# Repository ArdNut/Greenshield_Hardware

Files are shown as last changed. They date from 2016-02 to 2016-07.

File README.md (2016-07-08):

# Greenshield Hardware

This repository contains the design artifacts for the circuit and PCB layout
of the Greenshield Arduino shield created for chapter 10 of "Arduino: A Technical Reference".

These were creating using CadSoft's Eagle design tool version 6.5.0 for Linux.

Copyight 2015-2016 John M. Hughes

O'Reilly appreciates, but does not require, attribution. An attribution usually
includes the title, author, publisher, and ISBN. For example:

Arduino: A Technical Reference, by John M. Hughes. Copyright 2016 O’Reilly
Media, Inc., ISBN: 978-1-4919-2176-0.

If you feel your use of code examples falls outside fair use or the permission
given above, feel free to contact permissions@oreilly.com.

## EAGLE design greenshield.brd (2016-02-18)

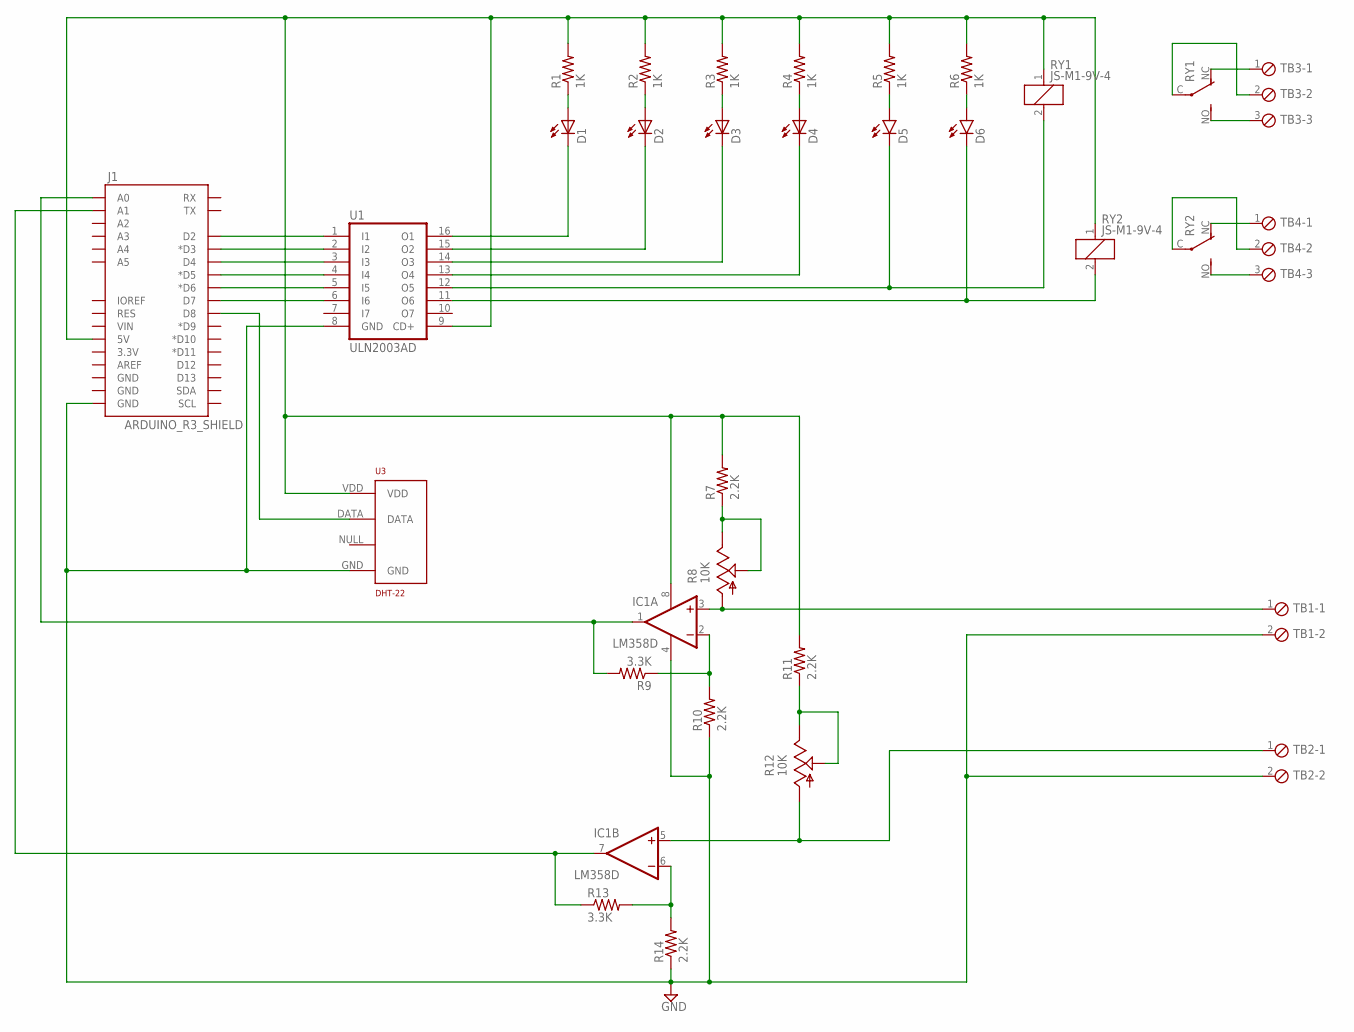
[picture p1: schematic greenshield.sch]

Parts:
D1, D2, D3, D4, D5, D6: LED3MM
IC1: LM358D; SO08
J1: ARDUINO_R3_SHIELD; UNO_R3_SHIELD
R1, R2, R3, R4, R5, R6: 1K; 0805
R7, R10, R11, R14: 2.2K; 0805
R8, R12: 10K; S64W
R9, R13: 3.3K; 0805
RY1, RY2: JS-M1-9V-4; JS-M
TB1, TB2: MPT2; 2POL254
TB3, TB4: MPT3; 3POL254
U1: ULN2003AD; SO16
U3: DHT-22; RHT03_DHT-22

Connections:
GND: IC1.4 (V-), J1.GND@0 (GND), R10.1, R14.1, TB1.2, TB2.2, U1.8 (GND), U3.GND
unnamed: J1.D2, U1.1 (I1)
unnamed: J1.D3 (*D3), U1.2 (I2)
unnamed: J1.D4, U1.3 (I3)
unnamed: D6.K (C), RY2.2, U1.11 (O6)
unnamed: J1.D5 (*D5), U1.4 (I4)
unnamed: J1.D6 (*D6), U1.5 (I5)
unnamed: J1.D7, U1.6 (I6)
unnamed: D5.K (C), RY1.2, U1.12 (O5)
unnamed: RY1.NC (O), TB3.1
unnamed: D1.K (C), U1.16 (O1)
unnamed: D6.A, R6.1
unnamed: D2.K (C), U1.15 (O2)
unnamed: D3.K (C), U1.14 (O3)
unnamed: D4.K (C), U1.13 (O4)
unnamed: D5.A, R5.1
unnamed: RY1.NO (S), TB3.3
unnamed: D1.A, R1.1
unnamed: D2.A, R2.1
unnamed: D3.A, R3.1
unnamed: D4.A, R4.1
unnamed: RY2.NC (O), TB4.1
unnamed: RY2.NO (S), TB4.3
unnamed: RY2.C, TB4.2
unnamed: RY1.C, TB3.2
unnamed: IC1.8 (V+), J1.5V, R1.2, R2.2, R3.2, R4.2, R5.2, R6.2, R7.2, R11.2, RY1.1, RY2.1, U1.9 (CD+), U3.VDD
unnamed: R7.1, R8.E, R8.S
unnamed: R11.1, R12.E, R12.S
unnamed: IC1.5 (+IN), R12.A, TB2.1
unnamed: IC1.6 (-IN), R13.2, R14.2
unnamed: IC1.7 (OUT), J1.A1, R13.1
unnamed: J1.D8, U3.DATA
unnamed: IC1.2 (-IN), R9.1, R10.2
unnamed: IC1.1 (OUT), J1.A0, R9.2
unnamed: IC1.3 (+IN), R8.A, TB1.1

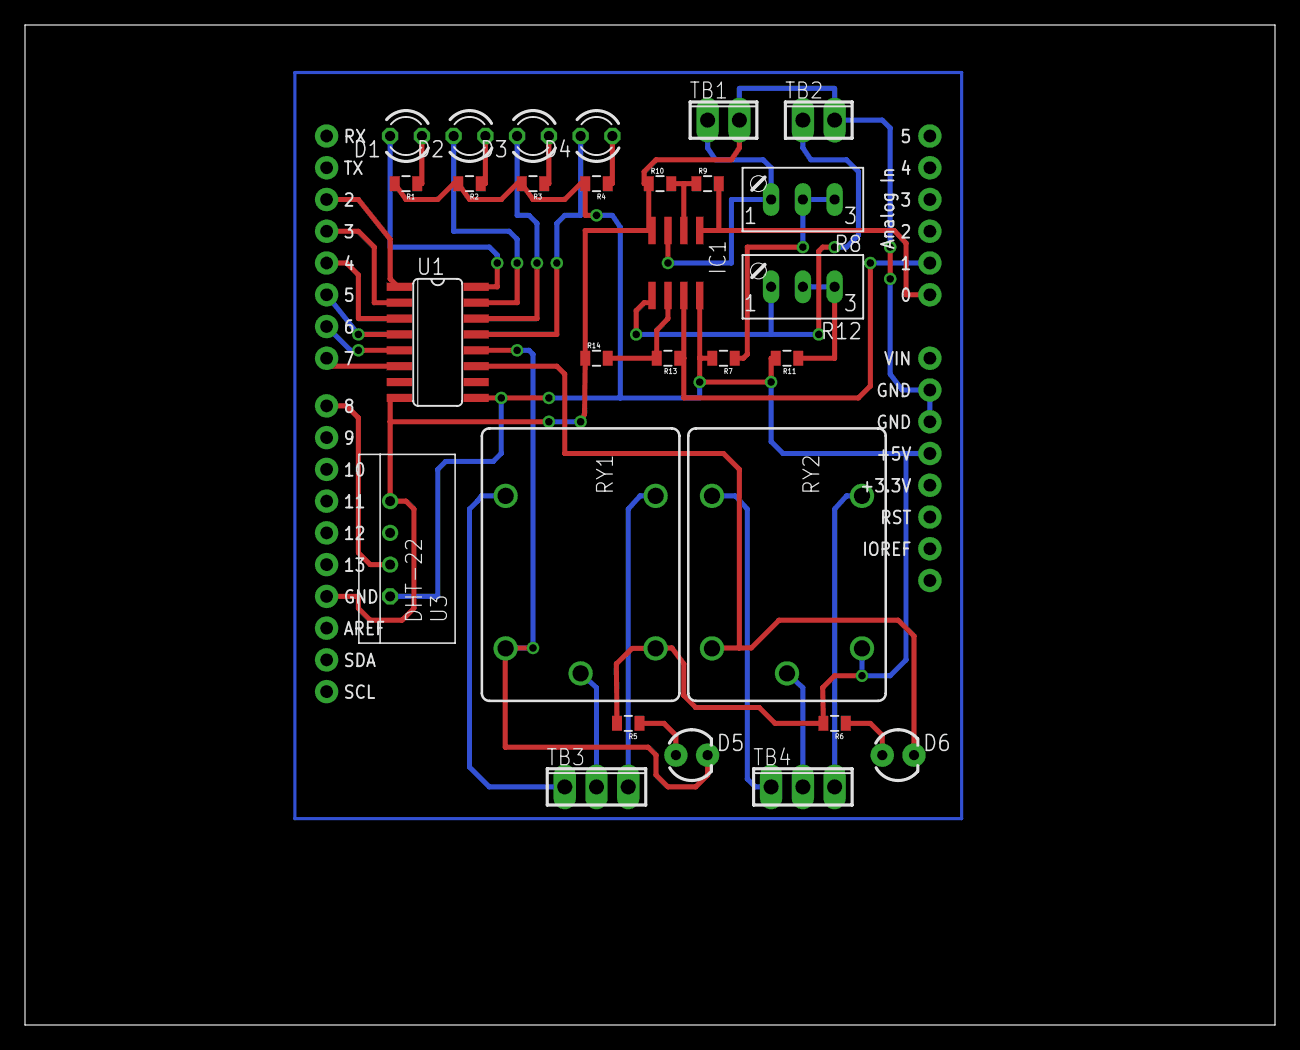
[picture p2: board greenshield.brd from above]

Board: 2 copper layers, 100.0 x 80.0 mm, 30 parts (0 on the bottom side), 35 nets.

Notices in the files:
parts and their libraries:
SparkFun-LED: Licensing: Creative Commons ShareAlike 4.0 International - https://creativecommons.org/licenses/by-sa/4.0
